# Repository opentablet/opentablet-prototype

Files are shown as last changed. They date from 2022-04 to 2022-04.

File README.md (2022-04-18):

# opentablet

A small drawing-tablet like input device with high (1kHz) polling rates and low latency, designed to be compatible with a small number of Wacom pens. Only supports position tracking, not clicking or pen pressure.

This version was an early prototype. The analog front end has several shortcomings (noisy and limited range) and is overly complex for its intended task. Next version should solve these issues.

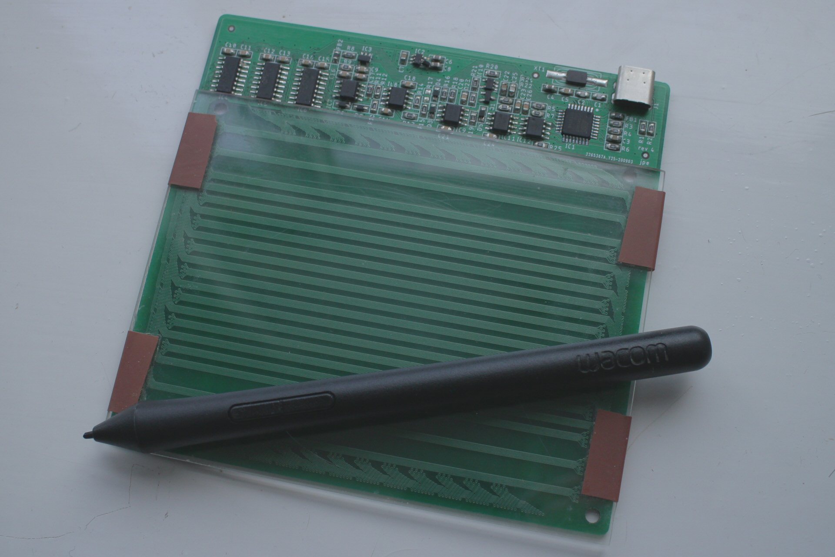
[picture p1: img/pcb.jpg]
PCB photo


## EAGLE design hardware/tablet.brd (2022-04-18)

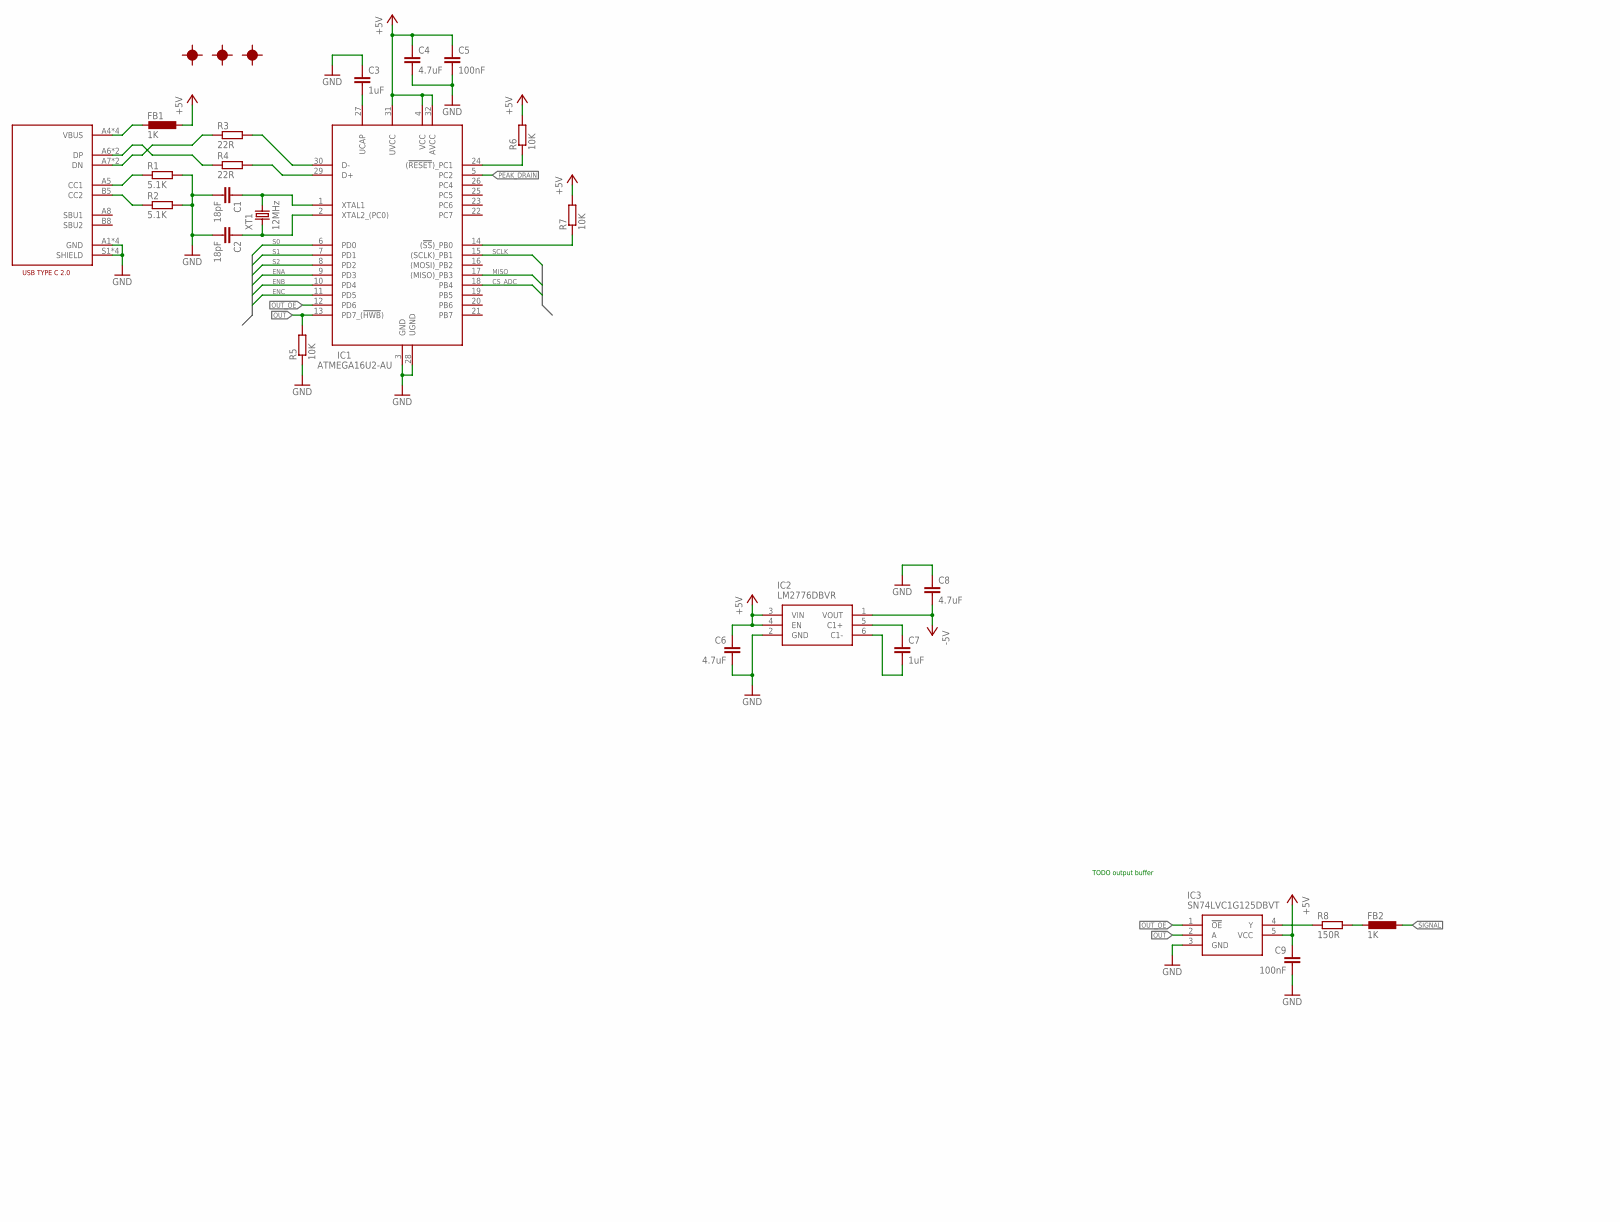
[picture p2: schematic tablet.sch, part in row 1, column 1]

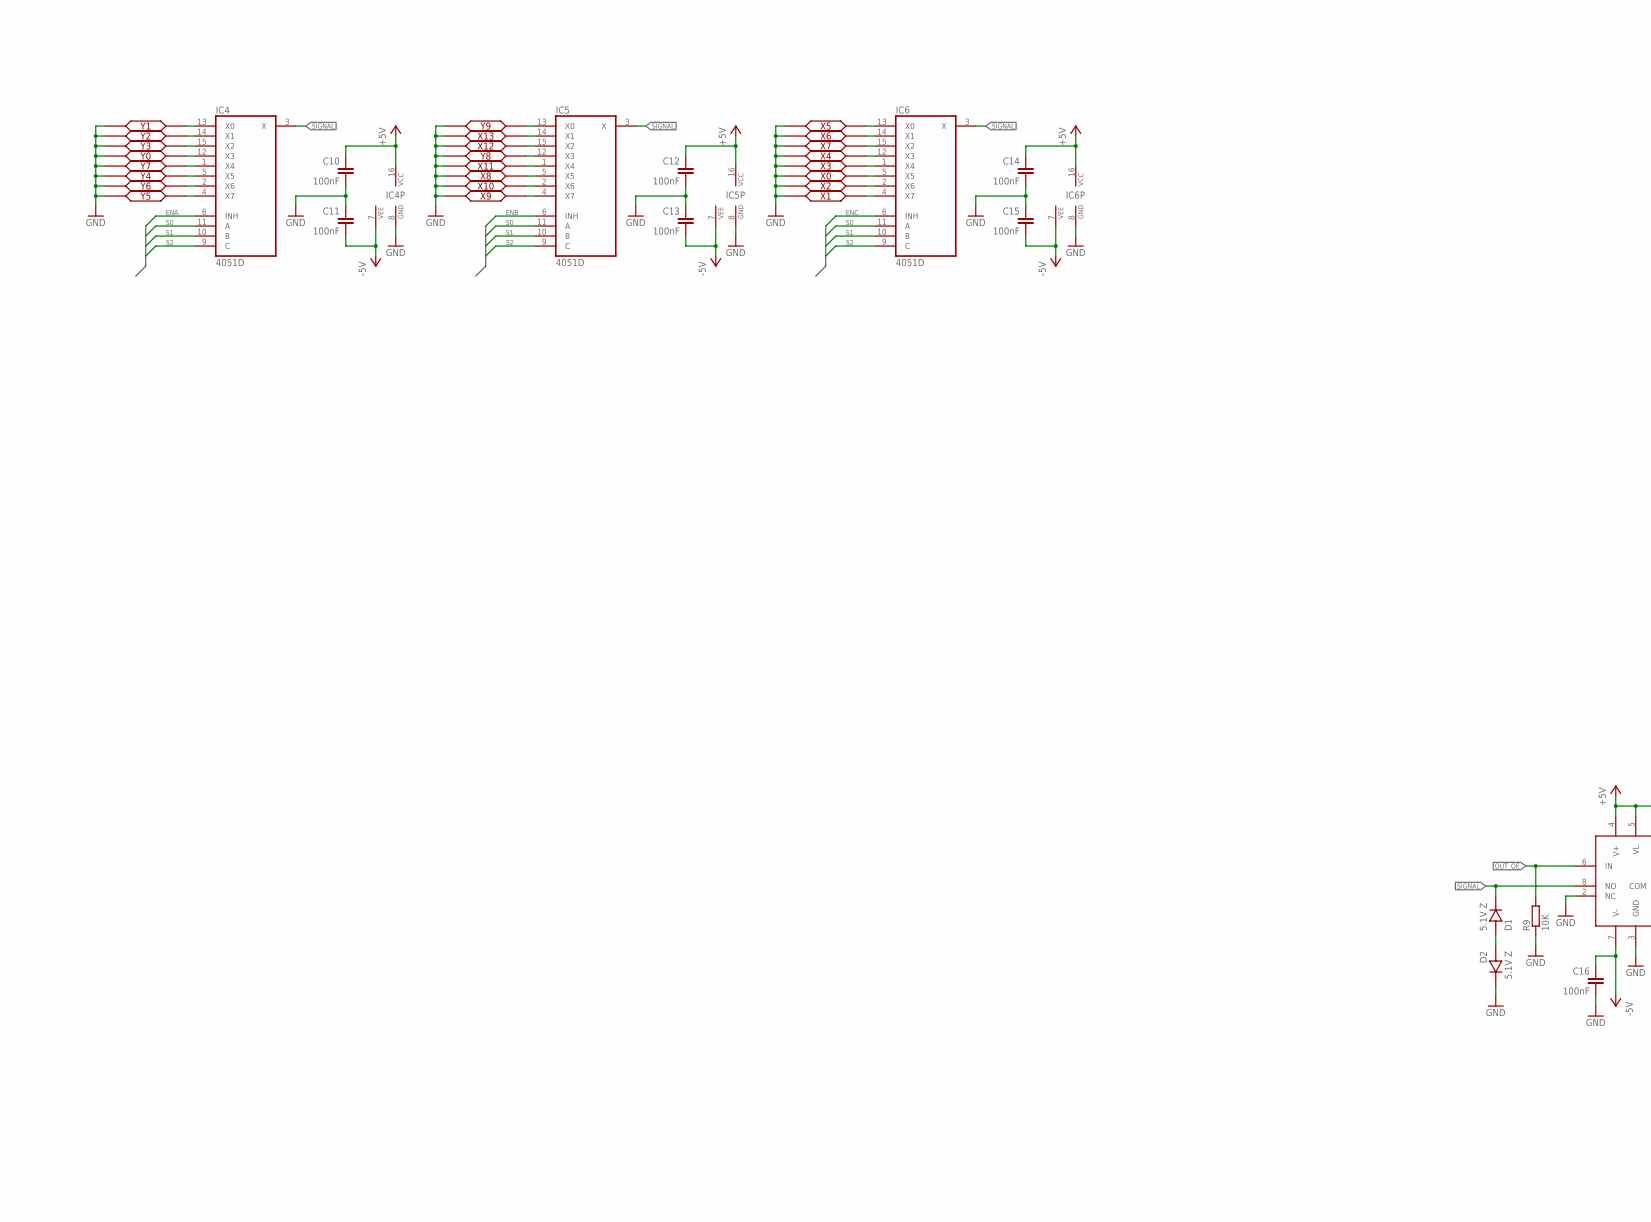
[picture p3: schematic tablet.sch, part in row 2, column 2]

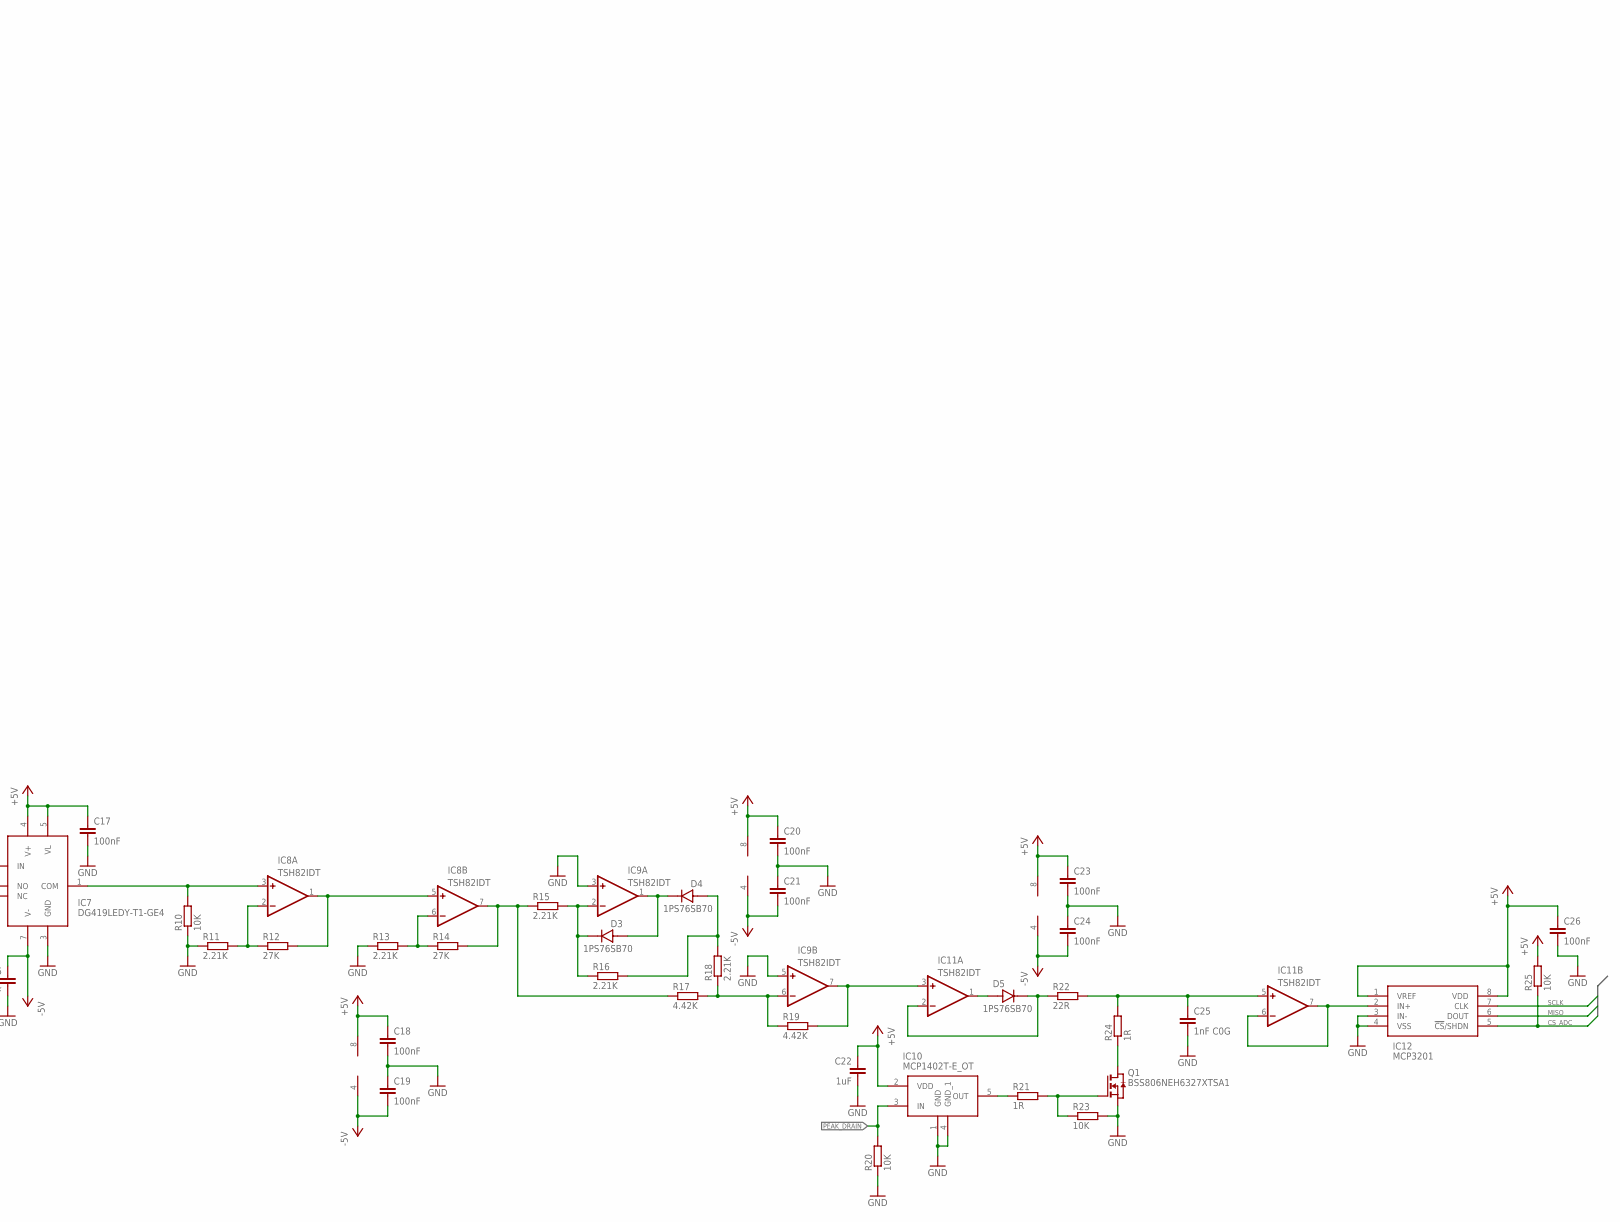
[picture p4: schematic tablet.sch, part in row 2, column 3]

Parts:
C1, C2: 18pF; 0805
C3, C7, C22: 1uF; 0805
C4, C6, C8: 4.7uF; 0805
C5, C9, C10, C11, C12, C13, C14, C15, C16, C17, C18, C19, C20, C21, C23, C24, C26: 100nF; 0805
C25: 1nF C0G; 0805
D1, D2: 5.1V Z; SOD323
D3, D4, D5: 1PS76SB70; SOD323
FB1, FB2: 1K; 0805
FD1, FD2, FD3: FIDUCIAL1_2; FIDUCIAL
IC1: ATMEGA16U2-AU; QFP80P900X900X120-32N
IC2: LM2776DBVR; SOT95P280X145-6N
IC3: SN74LVC1G125DBVT; SOT95P280X145-5N
IC4, IC5, IC6: 4051D; SO16
IC7: DG419LEDY-T1-GE4; SOIC8
IC8, IC9, IC11: TSH82IDT; SOIC8
IC10: MCP1402T-E_OT; SOT95P270X145-5N
IC12: MCP3201; SOIC8
J1: USB4085-GF-A
Q1: BSS806NEH6327XTSA1; SOT23_3
R1, R2: 5.1K; 0805
R3, R4, R22: 22R; 0805
R5, R6, R7, R9, R10, R20, R23, R25: 10K; 0805
R8: 150R; 0805
R11, R13, R15, R16, R18: 2.21K; 0805
R12, R14: 27K; 0805
R17, R19: 4.42K; 0805
R21, R24: 1R; 0805
X0, X1, X2, X3, X4, X5, X6, X7, X8, X9, X10, X11, X12, X13: 2P
XT1: 12MHz; HC49UP
Y0, Y1, Y2, Y3, Y4, Y5, Y6, Y7, Y8, Y9: 2P

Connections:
+5V: C4.1, C5.1, C6.1, C9.1, C10.1, C12.1, C14.1, C17.1, C18.1, C20.1, C22.1, C23.1, C26.1, FB1.1, IC1.4 (VCC), IC1.31 (UVCC), IC1.32 (AVCC), IC2.3 (VIN), IC2.4 (EN), IC3.5 (VCC), IC4.16 (VCC), IC5.16 (VCC), IC6.16 (VCC), IC7.4 (V+), IC7.5 (VL), IC8.8 (V+), IC9.8 (V+), IC10.2 (VDD), IC11.8 (V+), IC12.1 (VREF), IC12.8 (VDD), R6.2, R7.2, R25.2
-5V: C8.2, C11.2, C13.2, C15.2, C16.1, C19.2, C21.2, C24.2, IC2.1 (VOUT), IC4.7 (VEE), IC5.7 (VEE), IC6.7 (VEE), IC7.7 (V-), IC8.4 (V-), IC9.4 (V-), IC11.4 (V-)
CS_ADC: IC1.18 (PB4), IC12.5 (!CS!/SHDN), R25.1
ENA: IC1.9 (PD3), IC4.6 (INH)
ENB: IC1.10 (PD4), IC5.6 (INH)
ENC: IC1.11 (PD5), IC6.6 (INH)
GND: C1.2, C2.2, C3.1, C4.2, C5.2, C6.2, C8.1, C9.2, C10.2, C11.1, C12.2, C13.1, C14.2, C15.1, C16.2, C17.2, C18.2, C19.1, C20.2, C21.1, C22.2, C23.2, C24.1, C25.2, C26.2, D2.2, IC1.3 (GND), IC1.28 (UGND), IC2.2 (GND), IC3.3 (GND), IC4.8 (GND), IC5.8 (GND), IC6.8 (GND), IC7.2 (NC), IC7.3 (GND), IC9.3 (+IN), IC9.5 (+IN), IC10.1 (GND), IC10.4 (GND_1), IC12.3 (IN-), IC12.4 (VSS), J1.A1 (GND), J1.A12 (GND), J1.B1 (GND), J1.B12 (GND), J1.S1 (SHIELD), J1.S2 (SHIELD), J1.S3 (SHIELD), J1.S4 (SHIELD), Q1.P$2 (S), R1.2, R2.2, R5.1, R9.1, R10.1, R11.1, R13.1, R20.1, R23.2, X0.2, X1.2, X2.2, X3.2, X4.2, X5.2, X6.2, X7.2, X8.2, X9.2, X10.2, X11.2, X12.2, X13.2, Y0.2, Y1.2, Y2.2, Y3.2, Y4.2, Y5.2, Y6.2, Y7.2, Y8.2, Y9.2
MISO: IC1.17 ((MISO)_PB3), IC12.6 (DOUT)
unnamed: C1.1, IC1.1 (XTAL1), XT1.2
unnamed: D1.1, D2.1
unnamed: IC3.4 (Y), R8.1
unnamed: IC8.2 (-IN), R11.2, R12.1
unnamed: C25.1, IC11.5 (+IN), R22.2, R24.2
unnamed: C3.2, IC1.27 (UCAP)
unnamed: C2.1, IC1.2 (XTAL2_(PC0)), XT1.1
unnamed: FB1.2, J1.A4 (VBUS), J1.A9 (VBUS), J1.B4 (VBUS), J1.B9 (VBUS)
unnamed: IC8.7 (OUT), R14.2, R15.1, R17.1
unnamed: IC8.1 (OUT), IC8.5 (+IN), R12.2
unnamed: D3.2, IC9.2 (-IN), R15.2, R16.1
unnamed: J1.A5 (CC1), R1.1
unnamed: IC8.6 (-IN), R13.2, R14.1
unnamed: J1.B5 (CC2), R2.1
unnamed: D3.1, D4.2, IC9.1 (OUT)
unnamed: D4.1, R16.2, R18.2
unnamed: IC9.6 (-IN), R17.2, R18.1, R19.1
unnamed: Q1.P$1 (G), R21.2, R23.1
unnamed: D5.1, IC11.1 (OUT)
unnamed: IC9.7 (OUT), IC11.3 (+IN), R19.2
unnamed: D5.2, IC11.2 (-IN), R22.1
unnamed: IC1.14 ((!SS!)_PB0), R7.1
unnamed: IC1.24 ((!RESET!)_PC1), R6.1
unnamed: IC11.6 (-IN), IC11.7 (OUT), IC12.2 (IN+)
unnamed: IC1.29 (D+), R4.2
unnamed: IC7.1 (COM), IC8.3 (+IN), R10.2
unnamed: IC1.30 (D-), R3.2
unnamed: J1.A7 (DN), J1.B7 (DN), R3.1
unnamed: J1.A6 (DP), J1.B6 (DP), R4.1
unnamed: Q1.P$3 (D), R24.1
unnamed: IC10.5 (OUT), R21.1
unnamed: C7.1, IC2.5 (C1+)
unnamed: C7.2, IC2.6 (C1-)
unnamed: FB2.2, R8.2
OUT: IC1.13 (PD7_(!HWB!)), IC3.2 (A), R5.2
OUT_OE: IC1.12 (PD6), IC3.1 (!OE), IC7.6 (IN), R9.2
PEAK_DRAIN: IC1.5 (PC2), IC10.3 (IN), R20.2
S0: IC1.6 (PD0), IC4.11 (A), IC5.11 (A), IC6.11 (A)
S1: IC1.7 (PD1), IC4.10 (B), IC5.10 (B), IC6.10 (B)
S2: IC1.8 (PD2), IC4.9 (C), IC5.9 (C), IC6.9 (C)
SCLK: IC1.15 ((SCLK)_PB1), IC12.7 (CLK)
SIGNAL: D1.2, FB2.1, IC4.3 (X), IC5.3 (X), IC6.3 (X), IC7.8 (NO)
X0: IC6.5 (X5), X0.1
X1: IC6.4 (X7), X1.1
X2: IC6.2 (X6), X2.1
X3: IC6.1 (X4), X3.1
X4: IC6.12 (X3), X4.1
X5: IC6.13 (X0), X5.1
X6: IC6.14 (X1), X6.1
X7: IC6.15 (X2), X7.1
X8: IC5.5 (X5), X8.1
X9: IC5.4 (X7), X9.1
X10: IC5.2 (X6), X10.1
X11: IC5.1 (X4), X11.1
X12: IC5.15 (X2), X12.1
X13: IC5.14 (X1), X13.1
Y0: IC4.12 (X3), Y0.1
Y1: IC4.13 (X0), Y1.1
Y2: IC4.14 (X1), Y2.1
Y3: IC4.15 (X2), Y3.1
Y4: IC4.5 (X5), Y4.1
Y5: IC4.4 (X7), Y5.1
Y6: IC4.2 (X6), Y6.1
Y7: IC4.1 (X4), Y7.1
Y8: IC5.12 (X3), Y8.1
Y9: IC5.13 (X0), Y9.1

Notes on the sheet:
TODO output buffer

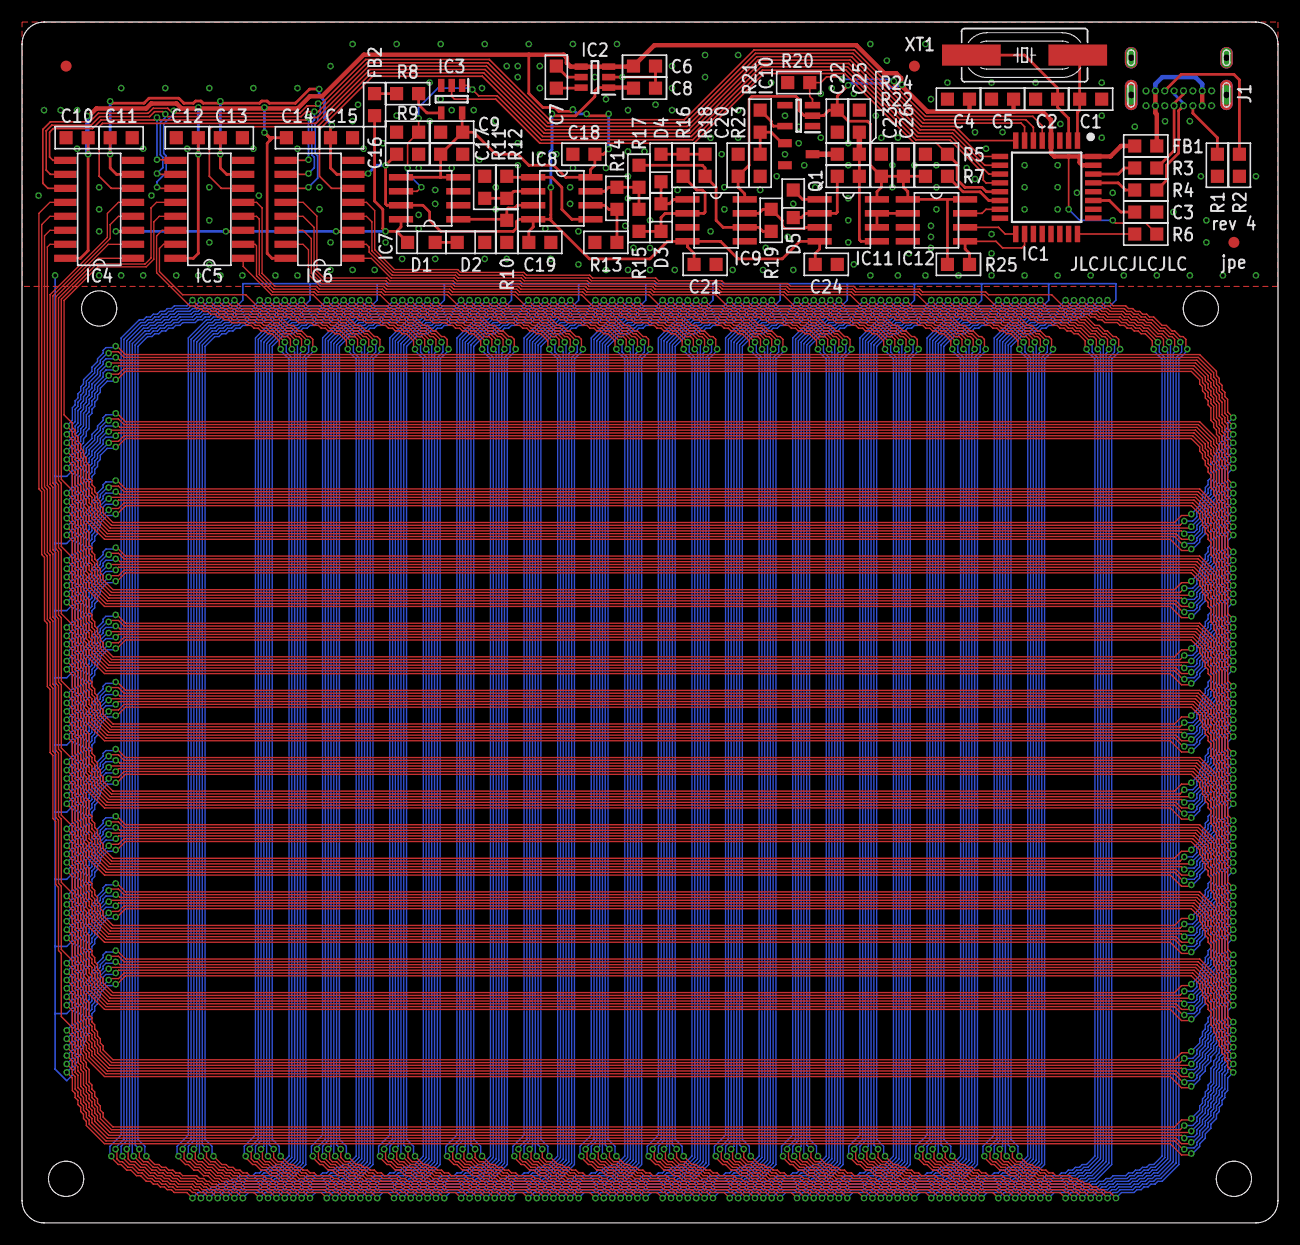
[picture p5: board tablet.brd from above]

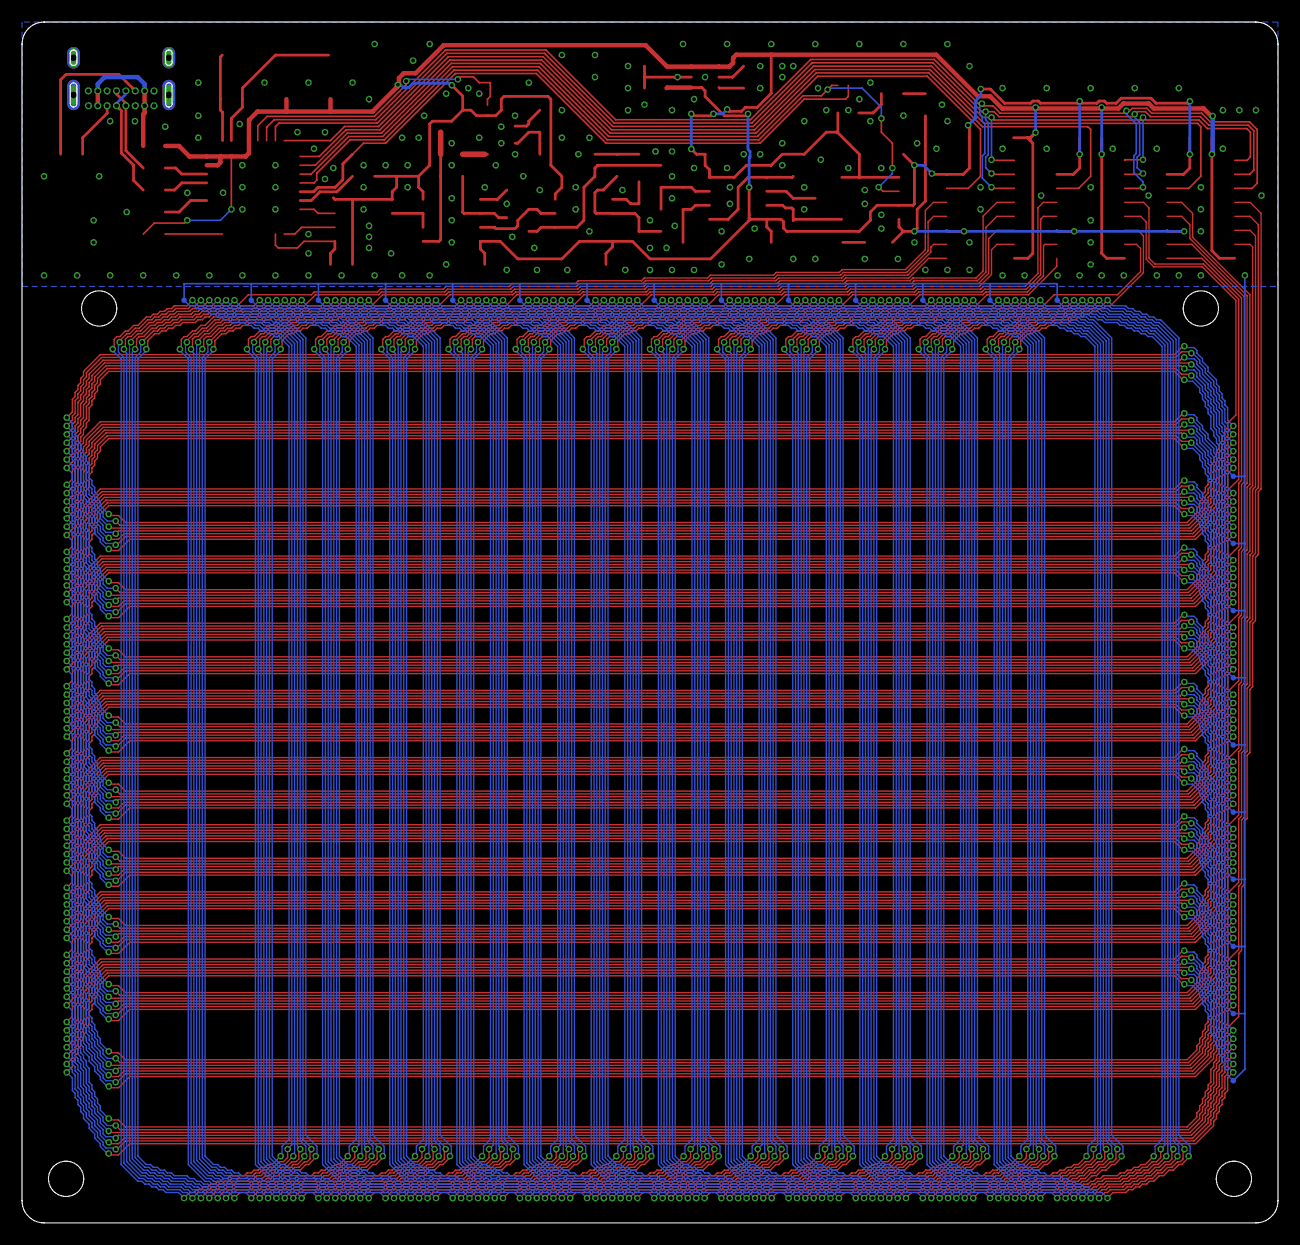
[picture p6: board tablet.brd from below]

Board: 2 copper layers, 114.0 x 109.0 mm, 100 parts (24 on the bottom side), 74 nets.

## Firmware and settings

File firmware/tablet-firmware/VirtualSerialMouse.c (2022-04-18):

/*
             LUFA Library
     Copyright (C) Dean Camera, 2017.

  dean [at] fourwalledcubicle [dot] com
           www.lufa-lib.org
*/

/*
  Copyright 2017  Dean Camera (dean [at] fourwalledcubicle [dot] com)

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
  The author disclaims all warranties with regard to this
  software, including all implied warranties of merchantability
  and fitness.  In no event shall the author be liable for any
  special, indirect or consequential damages or any damages
  whatsoever resulting from loss of use, data or profits, whether
  in an action of contract, negligence or other tortious action,
  arising out of or in connection with the use or performance of
  this software.
*/

/** \file
 *
 *  Main source file for the VirtualSerialMouse demo. This file contains the main tasks of
 *  the demo and is responsible for the initial application hardware configuration.
 */

#define S0 _BV(PD0)
#define S1 _BV(PD1)
#define S2 _BV(PD2)
#define OEA _BV(PD3)
#define OEB _BV(PD4)
#define OEC _BV(PD5)
#define OUT_OE _BV(PD6)
#define OUT _BV(PD7)

#define CS_ADC _BV(PB4)

#define PEAK_DRAIN _BV(PC2)

#define COLUMNS 14
#define ROWS 10

#define OFFSET 58

#include <stdlib.h>

#include "VirtualSerialMouse.h"

int16_t lastX = 16383;
int16_t lastY = 16383;

uint8_t columns[] = {
	S0 | 0  | S2 | OEA | OEB, // X0
	S0 | S1 | S2 | OEA | OEB, // X1
	0  | S1 | S2 | OEA | OEB, // X2
	0  | 0  | S2 | OEA | OEB, // X3
	S0 | S1 | 0  | OEA | OEB, // X4
	0  | 0  | 0  | OEA | OEB, // X5
	S0 | 0  | 0  | OEA | OEB, // X6
	0  | S1 | 0  | OEA | OEB, // X7
	S0 | 0  | S2 | OEA | OEC, // X8
	S0 | S1 | S2 | OEA | OEC, // X9
	0  | S1 | S2 | OEA | OEC, // X10
	0  | 0  | S2 | OEA | OEC, // X11
	0  | S1 | 0  | OEA | OEC, // X12
	S0 | 0  | 0  | OEA | OEC  // X13
};

uint8_t rows[] = {
	S0 | S1 | 0  | OEB | OEC, // Y0
	0  | 0  | 0  | OEB | OEC, // Y1
	S0 | 0  | 0  | OEB | OEC, // Y2
	0  | S1 | 0  | OEB | OEC, // Y3
	S0 | 0  | S2 | OEB | OEC, // Y4
	S0 | S1 | S2 | OEB | OEC, // Y5
	0  | S1 | S2 | OEB | OEC, // Y6
	0  | 0  | S2 | OEB | OEC, // Y7
	S0 | S1 | 0  | OEA | OEC, // Y8
	0  | 0  | 0  | OEA | OEC  // Y9
};

//volatile uint16_t field[6][4];

/** LUFA CDC Class driver interface configuration and state information. This structure is
 *  passed to all CDC Class driver functions, so that multiple instances of the same class
 *  within a device can be differentiated from one another.
 */
USB_ClassInfo_CDC_Device_t VirtualSerial_CDC_Interface =
	{
		.Config =
			{
				.ControlInterfaceNumber         = INTERFACE_ID_CDC_CCI,
				.DataINEndpoint                 =
					{
						.Address                = CDC_TX_EPADDR,
						.Size                   = CDC_TXRX_EPSIZE,
						.Banks                  = 1,
					},
				.DataOUTEndpoint                =
					{
						.Address                = CDC_RX_EPADDR,
						.Size                   = CDC_TXRX_EPSIZE,
						.Banks                  = 1,
					},
				.NotificationEndpoint           =
					{
						.Address                = CDC_NOTIFICATION_EPADDR,
						.Size                   = CDC_NOTIFICATION_EPSIZE,
						.Banks                  = 1,
					},
			},
	};

/** Buffer to hold the previously generated Mouse HID report, for comparison purposes inside the HID class driver. */
static uint8_t PrevMouseHIDReportBuffer[sizeof(USB_MouseReport_Data_t)];

/** LUFA HID Class driver interface configuration and state information. This structure is
 *  passed to all HID Class driver functions, so that multiple instances of the same class
 *  within a device can be differentiated from one another.
 */
USB_ClassInfo_HID_Device_t Mouse_HID_Interface =
	{
		.Config =
			{
				.InterfaceNumber                = INTERFACE_ID_Mouse,
				.ReportINEndpoint               =
					{
						.Address                = MOUSE_EPADDR,
						.Size                   = MOUSE_EPSIZE,
						.Banks                  = 1,
					},
				.PrevReportINBuffer             = PrevMouseHIDReportBuffer,
				.PrevReportINBufferSize         = sizeof(PrevMouseHIDReportBuffer),
			},
	};


/** Main program entry point. This routine contains the overall program flow, including initial
 *  setup of all components and the main program loop.
 */
int main(void)
{
	SetupHardware();
	GlobalInterruptEnable();

	DDRB |= _BV(PB0) | _BV(PB1) | _BV(PB2) | CS_ADC;
	PORTB |= _BV(PB4);
	PORTB &= ~(_BV(PB1) | _BV(PB2));
	PORTB |= _BV(PB0);
	//_delay_us(10);
	SPCR = ((1 << SPE) | (1 << MSTR) | (1 << SPR0));

	DDRD |= S0 | S1 | S2 | OEA | OEB | OEC | OUT_OE | OUT;
	PORTD |= OEA | OEB | OEC | OUT_OE;
	PORTD &= ~(S0 | S1 | S2 | OUT);

	DDRC |= PEAK_DRAIN;
	PORTC &= ~PEAK_DRAIN;

	for (;;)
	{
		/* Must throw away unused bytes from the host, or it will lock up while waiting for the device */
		CDC_Device_ReceiveByte(&VirtualSerial_CDC_Interface);

		CDC_Device_USBTask(&VirtualSerial_CDC_Interface);
		HID_Device_USBTask(&Mouse_HID_Interface);
		USB_USBTask();
	}
}

/** Configures the board hardware and chip peripherals for the demo's functionality. */
void SetupHardware(void)
{
	/* Disable watchdog if enabled by bootloader/fuses */
	MCUSR &= ~(1 << WDRF);
	wdt_disable();

	/* Disable clock division */
	clock_prescale_set(clock_div_1);

	/* Hardware Initialization */
	USB_Init();
}

/** Event handler for the library USB Connection event. */
void EVENT_USB_Device_Connect(void)
{

}

/** Event handler for the library USB Disconnection event. */
void EVENT_USB_Device_Disconnect(void)
{

}

/** Event handler for the library USB Configuration Changed event. */
void EVENT_USB_Device_ConfigurationChanged(void)
{
	bool ConfigSuccess = true;

	ConfigSuccess &= HID_Device_ConfigureEndpoints(&Mouse_HID_Interface);
	ConfigSuccess &= CDC_Device_ConfigureEndpoints(&VirtualSerial_CDC_Interface);

	USB_Device_EnableSOFEvents();
}

/** Event handler for the library USB Control Request reception event. */
void EVENT_USB_Device_ControlRequest(void)
{
	CDC_Device_ProcessControlRequest(&VirtualSerial_CDC_Interface);
	HID_Device_ProcessControlRequest(&Mouse_HID_Interface);
}

/** Event handler for the USB device Start Of Frame event. */
void EVENT_USB_Device_StartOfFrame(void)
{
	HID_Device_MillisecondElapsed(&Mouse_HID_Interface);
}

uint16_t read(uint8_t coil) {
	PORTD = coil;// | OUT_OE;
	//PORTD &= ~OUT_OE;

	for (uint8_t i = 0; i < 16; i++) {
		PORTD |= OUT;// 2 cycles
		asm volatile("nop"); // 11 cycles
		asm volatile("nop");
		asm volatile("nop");
		asm volatile("nop");
		asm volatile("nop");
		asm volatile("nop");
		asm volatile("nop");
		asm volatile("nop");
		asm volatile("nop");
		asm volatile("nop");
		asm volatile("nop");
		PORTD &= ~OUT;
		asm volatile("nop"); // 11 cycles
		asm volatile("nop");
		asm volatile("nop");
		asm volatile("nop");
		asm volatile("nop");
		asm volatile("nop");
		asm volatile("nop");
		asm volatile("nop");
		asm volatile("nop");
		asm volatile("nop");
		asm volatile("nop");
		PORTD |= OUT;// 2 cycles
		asm volatile("nop"); // 11 cycles
		asm volatile("nop");
		asm volatile("nop");
		asm volatile("nop");
		asm volatile("nop");
		asm volatile("nop");
		asm volatile("nop");
		asm volatile("nop");
		asm volatile("nop");
		asm volatile("nop");
		asm volatile("nop");
		PORTD &= ~OUT;
		asm volatile("nop"); // 12 cycles
		asm volatile("nop");
		asm volatile("nop");
		asm volatile("nop");
		asm volatile("nop");
		asm volatile("nop");
		asm volatile("nop");
		asm volatile("nop");
		asm volatile("nop");
		asm volatile("nop");
		asm volatile("nop");
		asm volatile("nop");
		PORTD |= OUT;// 2 cycles
		asm volatile("nop"); // 11 cycles
		asm volatile("nop");
		asm volatile("nop");
		asm volatile("nop");
		asm volatile("nop");
		asm volatile("nop");
		asm volatile("nop");
		asm volatile("nop");
		asm volatile("nop");
		asm volatile("nop");
		asm volatile("nop");
		PORTD &= ~OUT;// 2 cycles
		asm volatile("nop"); // 8 cycles (12 - end of loop cycles)
		asm volatile("nop");
		asm volatile("nop");
		asm volatile("nop");
		asm volatile("nop");
		asm volatile("nop");
		asm volatile("nop");
		asm volatile("nop");
		// end of loop compiles to subi (1 cycle), breq (1 cycle if staying in loop), rjmp (2 cycles)
	}
	
	PORTD |= OUT_OE;

	PORTC |= PEAK_DRAIN;
	asm volatile("nop"); // 7 cycles
	asm volatile("nop");
	/*asm volatile("nop");
	asm volatile("nop");
	asm volatile("nop");
	asm volatile("nop");
	asm volatile("nop");
	
	asm volatile("nop"); // 13 cycles
	asm volatile("nop");
	asm volatile("nop");
	asm volatile("nop");
	asm volatile("nop");
	asm volatile("nop");
	asm volatile("nop");
	asm volatile("nop");
	asm volatile("nop");
	asm volatile("nop");
	asm volatile("nop");
	asm volatile("nop");
	asm volatile("nop");*/
	PORTC &= ~PEAK_DRAIN;

	for (uint8_t i = 0; i < 16; i++) {
		asm volatile ("nop");
	}

	PORTB &= ~CS_ADC;

	PORTD &= ~OUT_OE;
	
	SPDR = 0;
	asm volatile("nop"); // bring loop in phase with spi interrupt, this actually makes the read a few cycles faster
	while (!(SPSR & (1 << SPIF)));
	
	uint16_t value = SPDR << 8;
	
	SPDR = 0;
	asm volatile("nop");
	while (!(SPSR & (1 << SPIF)));
	
	value |= SPDR;
	value = (value >> 1) & 0xFFF;
	
	PORTB |= CS_ADC;
	
	/*PORTC |= PEAK_DRAIN;
	for (uint8_t i = 0; i < 8; i++) {
		asm volatile ("nop");
	}
	PORTC &= ~PEAK_DRAIN;*/

	return value;
}

/** HID class driver callback function for the creation of HID reports to the host.
 *
 *  \param[in]     HIDInterfaceInfo  Pointer to the HID class interface configuration structure being referenced
 *  \param[in,out] ReportID    Report ID requested by the host if non-zero, otherwise callback should set to the generated report ID
 *  \param[in]     ReportType  Type of the report to create, either HID_REPORT_ITEM_In or HID_REPORT_ITEM_Feature
 *  \param[out]    ReportData  Pointer to a buffer where the created report should be stored
 *  \param[out]    ReportSize  Number of bytes written in the report (or zero if no report is to be sent)
 *
 *  \return Boolean \c true to force the sending of the report, \c false to let the library determine if it needs to be sent
 */
bool CALLBACK_HID_Device_CreateHIDReport(USB_ClassInfo_HID_Device_t* const HIDInterfaceInfo,
                                         uint8_t* const ReportID,
                                         const uint8_t ReportType,
                                         void* ReportData,
                                         uint16_t* const ReportSize)
{
	USB_MouseReport_Data_t* MouseReport = (USB_MouseReport_Data_t*)ReportData;

	MouseReport->X = lastX;
	MouseReport->Y = lastY;

	cli();

	int32_t wx = 0;
	int32_t cx = 0;

	//int32_t cr[] = {0, 0, 0, 0, 0, 0, 0, 0, 0, 0, 0, 0, 0, 0};

	for (uint8_t rx = 0; rx < 14; rx++) {
		uint8_t x = rx;
		if ((x & 1) == 1) x = 14 - x;
		int32_t value = (int32_t) read(columns[13 - x]);
		value -= OFFSET;
		if (value < 0) value = 0;
		if (value > 1100) value = 0;
		int32_t v = ((value * value) /*<< 1*/) + (value * /*6193*/3096);// + 4752;
		if (v < 0) v = 0;
		//if (v > 8285873) v = 8285873;
		if (v > 4142936) v = 4142936;
		wx += v;
		cx += v * x;
		//cr[x] = v;

		/*char str[6];
		itoa(value, str, 10);
		CDC_Device_SendString(&VirtualSerial_CDC_Interface, str);
		CDC_Device_SendString(&VirtualSerial_CDC_Interface, ",");*/
	}

	/*for (uint8_t x = 0; x < 14; x++) {
		char str[12];
		ltoa(cr[x], str, 10);
		CDC_Device_SendString(&VirtualSerial_CDC_Interface, str);
		CDC_Device_SendString(&VirtualSerial_CDC_Interface, ",");
	}
	char strw[12];
	ltoa(cx, strw, 10);
	CDC_Device_SendString(&VirtualSerial_CDC_Interface, strw);
	CDC_Device_SendString(&VirtualSerial_CDC_Interface, ",");
	char strc[12];
	ltoa(wx, strc, 10);
	CDC_Device_SendString(&VirtualSerial_CDC_Interface, strc);
	CDC_Device_SendString(&VirtualSerial_CDC_Interface, "\n");*/

	float tpx = (2730.58333333f/*2520.5f*//*38461538f*/) * ((((float) cx) / ((float) wx)) - 0.5f);
	if (tpx < 0) tpx = 0;
	if (tpx > 32767) tpx = 32767;
	int16_t penx = (int16_t) tpx;//((2730.58333333f/*2520.5f*//*38461538f*/) * (((float) cx) / ((float) wx)));

		/*char strx[6];
		itoa(penx, strx, 10);
		CDC_Device_SendString(&VirtualSerial_CDC_Interface, strx);
		CDC_Device_SendString(&VirtualSerial_CDC_Interface, ",");*/

	//if (penx < 0 || penx == 32767) CDC_Device_SendString(&VirtualSerial_CDC_Interface, " !!!!@@@@!!!!@@@@,");
	if (penx < 0) penx = 0;

	//CDC_Device_SendString(&VirtualSerial_CDC_Interface, "\n");

	int32_t wy = 0;
	int32_t cy = 0;

	for (uint8_t ry = 0; ry < 10; ry++) {
		uint8_t y = ry;
		if ((y & 1) == 1) y = 10 - y;
		int32_t value = (int32_t) read(rows[9 - y]);
		value -= OFFSET;
		if (value < 0) value = 0;
		if (value > 1100) value = 0;
		int32_t v = ((value * value) /*<< 1*/) + (value * /*6193*/3096);// + 4752;
		if (v < 0) v = 0;
		//if (v > 8285873) v = 8285873;
		if (v > 4142936) v = 4142936;
		wy += v;
		cy += v * y;
	}

	float tpy = (4095.875f/*3640.7f*//*77777778f*/) * ((((float) cy) / ((float) wy)) - 0.5f);
	if (tpy < 0) tpy = 0;
	if (tpy > 32767) tpy = 32767;
	int16_t peny = (int16_t) tpy;//((4095.875f/*3640.7f*//*77777778f*/) * (((float) cy) / ((float) wy)));
	
	/*char stry[6];
	itoa(peny, stry, 10);
	CDC_Device_SendString(&VirtualSerial_CDC_Interface, stry);
	CDC_Device_SendString(&VirtualSerial_CDC_Interface, "\n");*/

	if (peny < 0) peny = 0;
	
	lastX = penx;
	lastY = peny;

	//sei();

	if (wx < 828587 || wy < 828587) {
		*ReportSize = 0;
		return false;
	}

	MouseReport->X = penx;
	MouseReport->Y = peny;

	*ReportSize = sizeof(USB_MouseReport_Data_t);
	return true;
}

/** HID class driver callback function for the processing of HID reports from the host.
 *
 *  \param[in] HIDInterfaceInfo  Pointer to the HID class interface configuration structure being referenced
 *  \param[in] ReportID    Report ID of the received report from the host
 *  \param[in] ReportType  The type of report that the host has sent, either HID_REPORT_ITEM_Out or HID_REPORT_ITEM_Feature
 *  \param[in] ReportData  Pointer to a buffer where the received report has been stored
 *  \param[in] ReportSize  Size in bytes of the received HID report
 */
void CALLBACK_HID_Device_ProcessHIDReport(USB_ClassInfo_HID_Device_t* const HIDInterfaceInfo,
                                          const uint8_t ReportID,
                                          const uint8_t ReportType,
                                          const void* ReportData,
                                          const uint16_t ReportSize)
{
	// Unused (but mandatory for the HID class driver) in this demo, since there are no Host->Device reports
}

/** CDC class driver callback function the processing of changes to the virtual
 *  control lines sent from the host..
 *
 *  \param[in] CDCInterfaceInfo  Pointer to the CDC class interface configuration structure being referenced
 */
void EVENT_CDC_Device_ControLineStateChanged(USB_ClassInfo_CDC_Device_t *const CDCInterfaceInfo)
{
	/* You can get changes to the virtual CDC lines in this callback; a common
	   use-case is to use the Data Terminal Ready (DTR) flag to enable and
	   disable CDC communications in your application when set to avoid the
	   application blocking while waiting for a host to become ready and read
	   in the pending data from the USB endpoints.
	*/
	bool HostReady = (CDCInterfaceInfo->State.ControlLineStates.HostToDevice & CDC_CONTROL_LINE_OUT_DTR) != 0;
}

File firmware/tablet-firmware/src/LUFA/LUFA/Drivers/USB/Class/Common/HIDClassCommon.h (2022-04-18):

/*
             LUFA Library
     Copyright (C) Dean Camera, 2017.

  dean [at] fourwalledcubicle [dot] com
           www.lufa-lib.org
*/

/*
  Copyright 2017  Dean Camera (dean [at] fourwalledcubicle [dot] com)

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
  The author disclaims all warranties with regard to this
  software, including all implied warranties of merchantability
  and fitness.  In no event shall the author be liable for any
  special, indirect or consequential damages or any damages
  whatsoever resulting from loss of use, data or profits, whether
  in an action of contract, negligence or other tortious action,
  arising out of or in connection with the use or performance of
  this software.
*/

/** \file
 *  \brief Common definitions and declarations for the library USB HID Class driver.
 *
 *  Common definitions and declarations for the library USB HID Class driver.
 *
 *  \note This file should not be included directly. It is automatically included as needed by the USB module driver
 *        dispatch header located in LUFA/Drivers/USB.h.
 */

/** \ingroup Group_USBClassHID
 *  \defgroup Group_USBClassHIDCommon  Common Class Definitions
 *
 *  \section Sec_USBClassHIDCommon_ModDescription Module Description
 *  Constants, Types and Enum definitions that are common to both Device and Host modes for the USB
 *  HID Class.
 *
 *  @{
 */

#ifndef _HID_CLASS_COMMON_H_
#define _HID_CLASS_COMMON_H_

	/* Includes: */
		#include "../../Core/StdDescriptors.h"
		#include "HIDParser.h"

	/* Enable C linkage for C++ Compilers: */
		#if defined(__cplusplus)
			extern "C" {
		#endif

	/* Preprocessor Checks: */
		#if !defined(__INCLUDE_FROM_HID_DRIVER)
			#error Do not include this file directly. Include LUFA/Drivers/USB.h instead.
		#endif

	/* Macros: */
		/** \name Keyboard Standard Report Modifier Masks */
		//@{
		/** Constant for a keyboard report modifier byte, indicating that the keyboard's left control key is currently pressed. */
		#define HID_KEYBOARD_MODIFIER_LEFTCTRL                    (1 << 0)

		/** Constant for a keyboard report modifier byte, indicating that the keyboard's left shift key is currently pressed. */
		#define HID_KEYBOARD_MODIFIER_LEFTSHIFT                   (1 << 1)

		/** Constant for a keyboard report modifier byte, indicating that the keyboard's left alt key is currently pressed. */
		#define HID_KEYBOARD_MODIFIER_LEFTALT                     (1 << 2)

		/** Constant for a keyboard report modifier byte, indicating that the keyboard's left GUI key is currently pressed. */
		#define HID_KEYBOARD_MODIFIER_LEFTGUI                     (1 << 3)

		/** Constant for a keyboard report modifier byte, indicating that the keyboard's right control key is currently pressed. */
		#define HID_KEYBOARD_MODIFIER_RIGHTCTRL                   (1 << 4)

		/** Constant for a keyboard report modifier byte, indicating that the keyboard's right shift key is currently pressed. */
		#define HID_KEYBOARD_MODIFIER_RIGHTSHIFT                  (1 << 5)

		/** Constant for a keyboard report modifier byte, indicating that the keyboard's right alt key is currently pressed. */
		#define HID_KEYBOARD_MODIFIER_RIGHTALT                    (1 << 6)

		/** Constant for a keyboard report modifier byte, indicating that the keyboard's right GUI key is currently pressed. */
		#define HID_KEYBOARD_MODIFIER_RIGHTGUI                    (1 << 7)
		//@}

		/** \name Keyboard Standard Report LED Masks */
		//@{
		/** Constant for a keyboard output report LED byte, indicating that the host's NUM LOCK mode is currently set. */
		#define HID_KEYBOARD_LED_NUMLOCK                          (1 << 0)

		/** Constant for a keyboard output report LED byte, indicating that the host's CAPS LOCK mode is currently set. */
		#define HID_KEYBOARD_LED_CAPSLOCK                         (1 << 1)

		/** Constant for a keyboard output report LED byte, indicating that the host's SCROLL LOCK mode is currently set. */
		#define HID_KEYBOARD_LED_SCROLLLOCK                       (1 << 2)

		/** Constant for a keyboard output report LED byte, indicating that the host's COMPOSE mode is currently set. */
		#define HID_KEYBOARD_LED_COMPOSE                          (1 << 3)

		/** Constant for a keyboard output report LED byte, indicating that the host's KANA mode is currently set. */
		#define HID_KEYBOARD_LED_KANA                             (1 << 4)
		//@}
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
